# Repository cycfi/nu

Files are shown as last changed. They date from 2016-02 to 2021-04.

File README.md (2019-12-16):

The Nu Series Modular Active Pickups are hacker friendly, general purpose pickups 
that can be used in a variety of applications. These are active multichannel 
pickups with low impedance coils and integrated single-ended, low-power, 
low-noise preamplifier for each coil. The Neodymium-core pickups are low profile 
and modular. They can be used individually or in groups.

This is the next evolutionary stage of our flagship multichannel Neo pickup. The 
Nu sports better crosstalk performance using permalloy ring shields and even 
lower noise with improved discrete preamp design. Most importantly, they sound 
just as good as the original. Same coil, same magnetic structure.

The pickups are designed for polyphonic effects processing —one for each string 
(distortion, EQ, compressor, delay, pan, pitch-shift, etc). Such extensive 
processing is now very possible due to advances in digital signal processing and 
multi-channel audio interfaces and multi-track audio software becoming commonplace.

The modular pickups are not just for guitars. Nus can also be utilized for other 
musical instruments such as the bass guitar, harps, pianos, xylophones, etc. The 
Nus are perfect for fanned-fret electric guitars with the pickup poles positioned 
at various angles. 

Refer to this repository to get the Eagle libraries used in our schematic and pcb files: https://github.com/cycfi/eagle_common

This work is licensed under a [Creative Commons Attribution-NonCommercial 4.0 
International License](http://creativecommons.org/licenses/by-nc/4.0/).

http://www.cycfi.com/

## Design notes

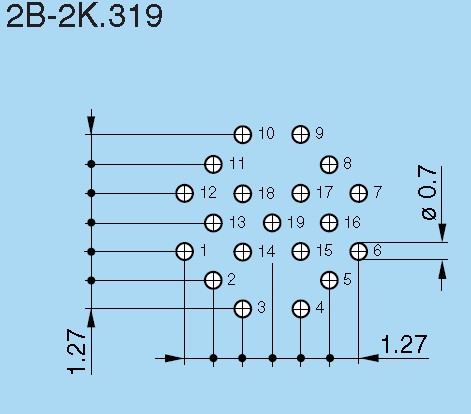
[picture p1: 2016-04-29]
references/19p_lemo_connector/sz_receptacle_90deg/pcb_pin_position.jpg

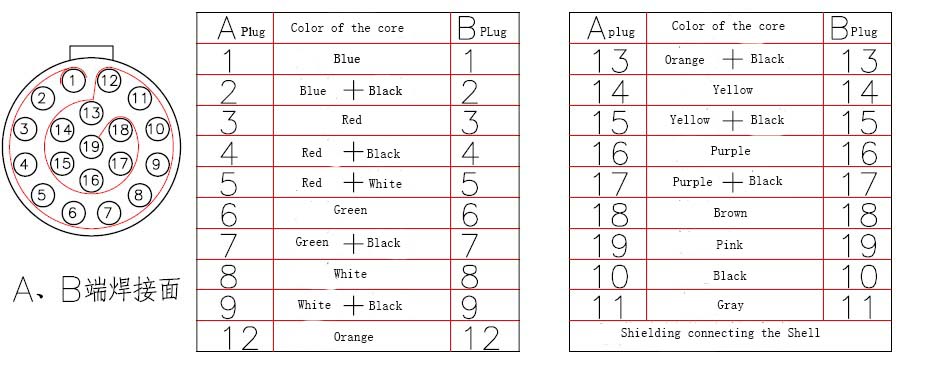
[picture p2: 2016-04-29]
references/19p_lemo_connector/sz_receptacle/pin_position_b.jpg

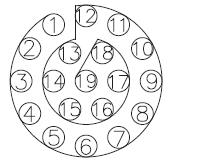
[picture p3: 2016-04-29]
references/19p_lemo_connector/sz_receptacle/pin_position_a.png

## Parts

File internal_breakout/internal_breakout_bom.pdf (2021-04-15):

INTERNAL BREAKOUT
Item | Description | Part Number | Packaging | Manufacturer | Location | Qty.
1 | 1uF | CC0603KRX5R8BB105 | C0603 | TDK | C3 | 1
2 | 10nF | CC0402KRX7R8BB103 | C0402 | Murata | C4 | 1
3 | 2.2uF | GRM188R6YA225KA12D | C0603 | Murata | C6 | 1
4 | 1nF | GCM155L81H102KA37D | C0402 | KEMET | C5 | 1
5 | 10uF | GRM188R61E106KA73D | C0603 | TDK | C1, C2 | 2
6 | 2x5 Male Header TH | M22-2580505 | 2.00mm | Harwin | J3, J4, J10, J11 | 4
7 | 1x3Male Header TH | 22-28-4035 | 2.54mm | Molex | J1, J2, J5, J6, J7, J8, J9, J10, J11, J12, J13, J14, J15 | 13
8 | P-Channel MOSFET | DMP3099L-7 | SOT-23-3 | Diodes Incorporated | Q1 | 1
9 | LDO Voltage Regulator | LP2985-10DBVR | SOT-23-5 | Texas Instruments | U1 | 1
10 | Ferrite Bead | BLM18KG700TN1D | R0603 | | FB1 | 1

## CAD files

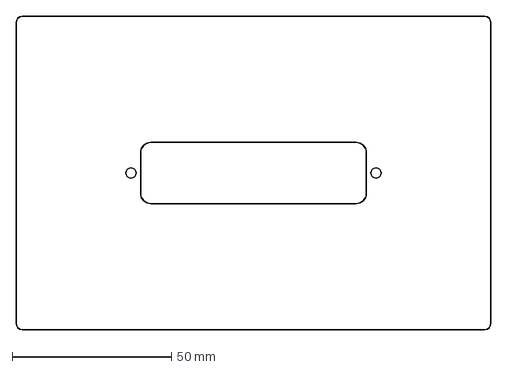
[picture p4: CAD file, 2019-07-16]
cad_drawings/nu_multi/Nu_Multi_6_Routing_Template_Drawing.DXF
149.2 x 98.4 mm

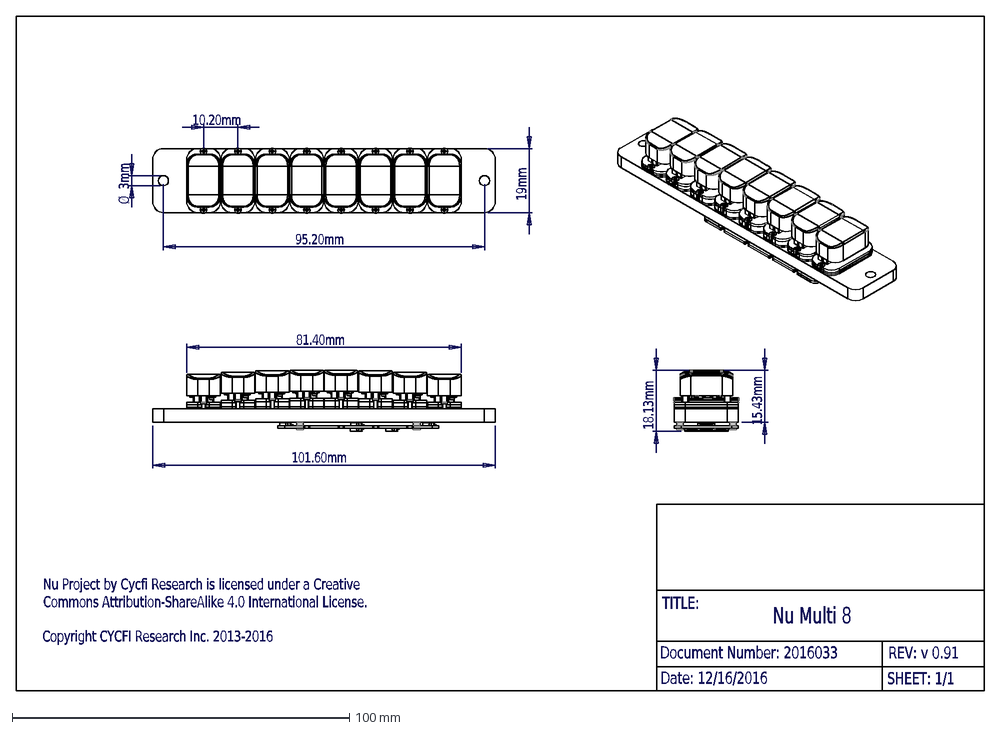
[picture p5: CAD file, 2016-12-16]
CAD_Drawings/Nu_Multi/Nu_Multi_8.dxf
Nu Project by Cycfi Research is licensed under a Creative
Commons Attribution-ShareAlike 4.0 International License.
Copyright CYCFI Research Inc. 2013-2016
Nu Multi 8
TITLE:
Document Number: 2016033
Date: 12/16/2016
REV: v 0.91
SHEET: 1/1
81.40mm
101.60mm
10.20mm
19mm
95.20mm
Ø
3mm
15.43mm
18.13mm

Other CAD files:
cad_drawings/nu_multi/nu_multi_7.DWG
cad_drawings/nu_multi/nu_multi_6.DWG
cad_drawings/nu_multi/nu_multi_8.DWG

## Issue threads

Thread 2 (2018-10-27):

Nu6_Multi.pdf?

olavkvern, 2018-10-27:
Hi CycFi--I'm finally getting around to putting a Nu Multi 6 pickup into a current project, and I came here looking for the technical drawings. The link to the Nu6_Multi.pdf file returns a 404 error, and I don't see the PDF here. Where would I find it?

Thanks,

Ole
okvern@ix.netcom.com

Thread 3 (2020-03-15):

incomplete BOM

bobwmcgrath, 2020-03-15:
Hello.  I am a long time fan of cycfi research's work.  I was curious about the construction of the pickup part of this nu capsule, but I do not see the "neodymium magnet, iron core, pickup coil, or permalloy ring"  that is shown on the website.   Can you please point me in the right direction to learn more about this?  Are these off the shelf parts or custom machined?  If they are custom made is there CAD information for the parts.  Thanks!

djowel, 2020-03-15:
Hi Bob, RIght. Well, these are not off the shelf parts, except for the neodymium magnet, which is kinda standard N52 disc types. We make these ourselves. We do have 3D drawings that I can place here.

bobwmcgrath, 2020-05-01:
That would be fantastic.

jonnor, 2022-11-05:
What are the rough specs on the coil? Size, inductance, etc? Would it be feasible at all to use off-the-shell inductor (SMD or throughhole) as a single string pickup?

djowel, 2022-11-06:
You can find the specs here:
https://www.cycfi.com/projects/nu-v2-capsule/

No, it is not possible to use off-the-shell inductors, or at least there's none that I know of that will fit the dimensions of the capsule and the magnet. I'm attaching the drawings for the coil.

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

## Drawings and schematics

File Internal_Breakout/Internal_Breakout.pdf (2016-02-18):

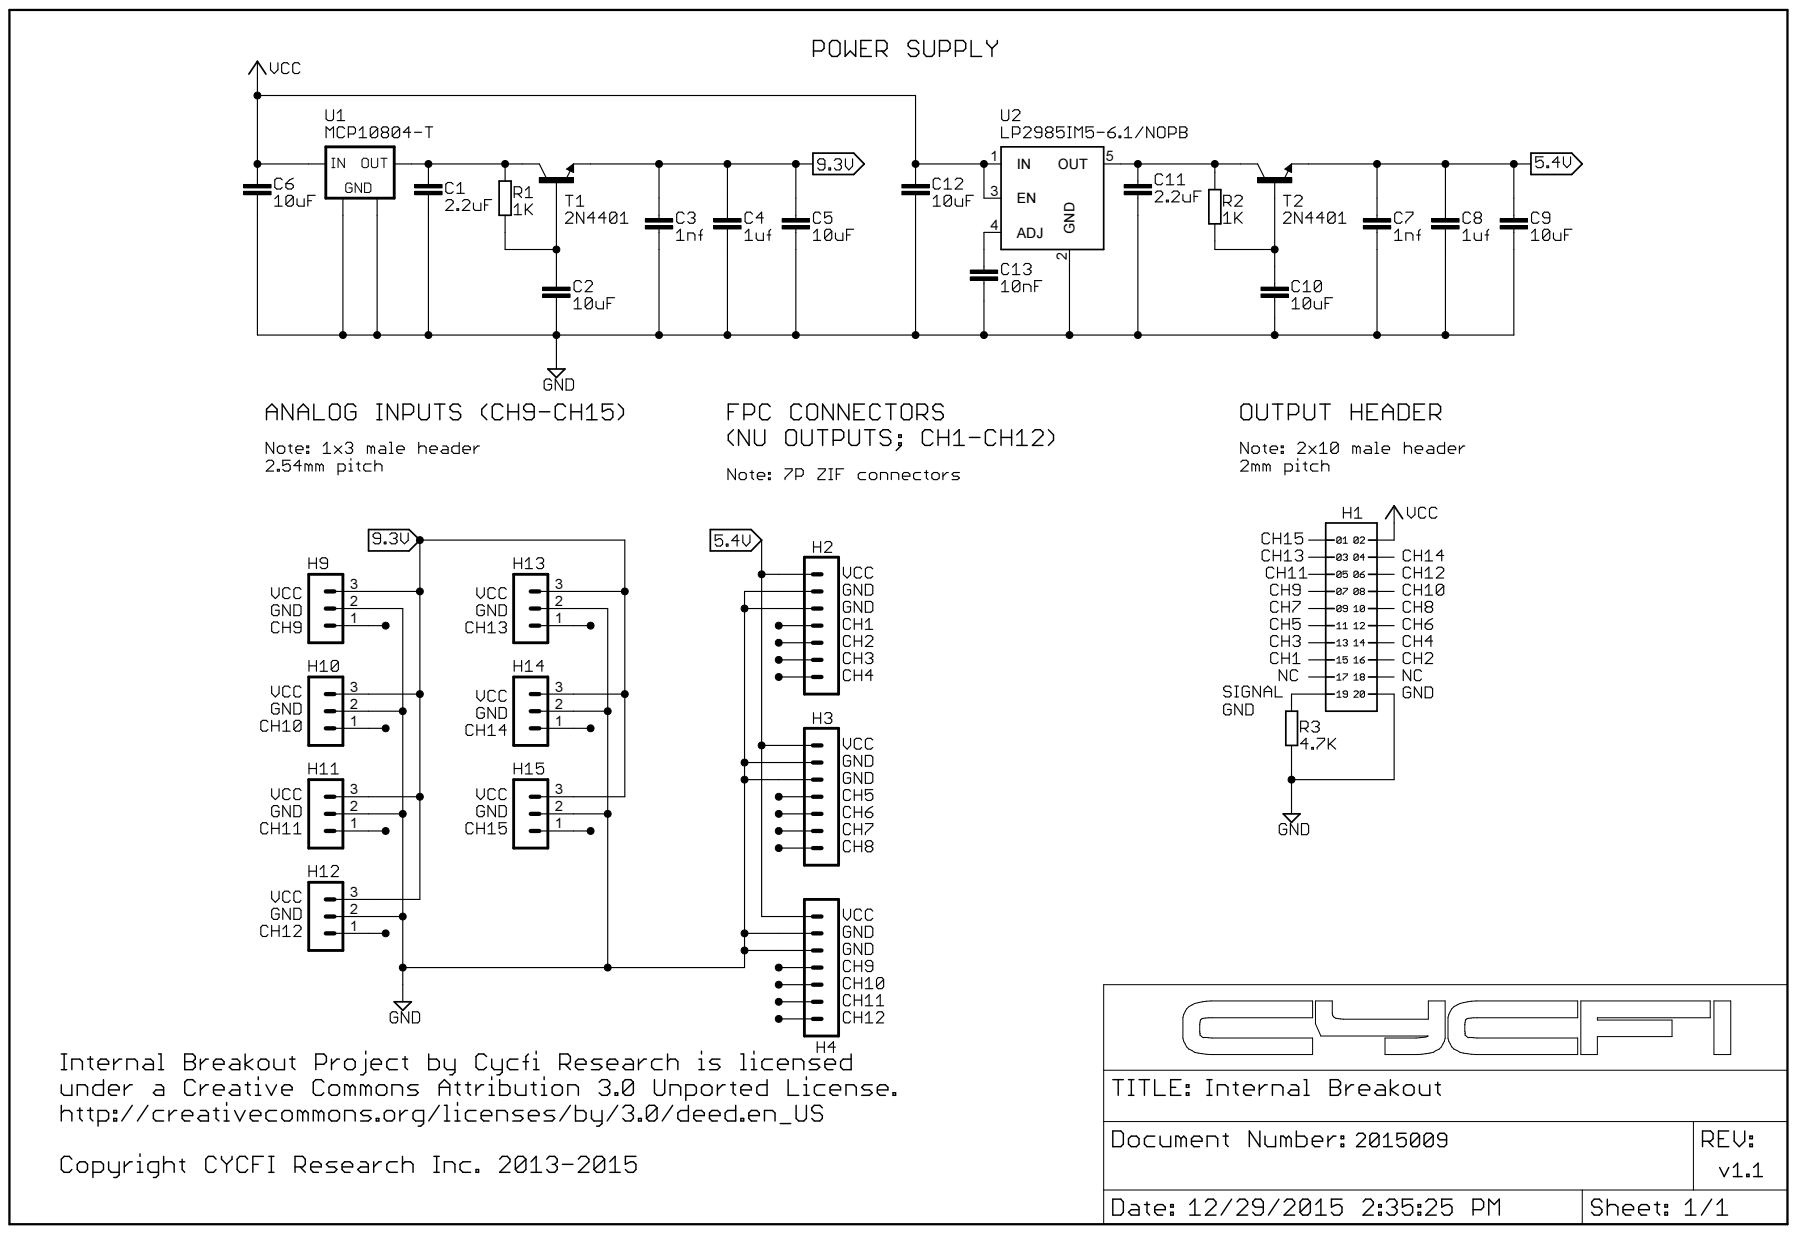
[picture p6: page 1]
OUT; ADJ; GND

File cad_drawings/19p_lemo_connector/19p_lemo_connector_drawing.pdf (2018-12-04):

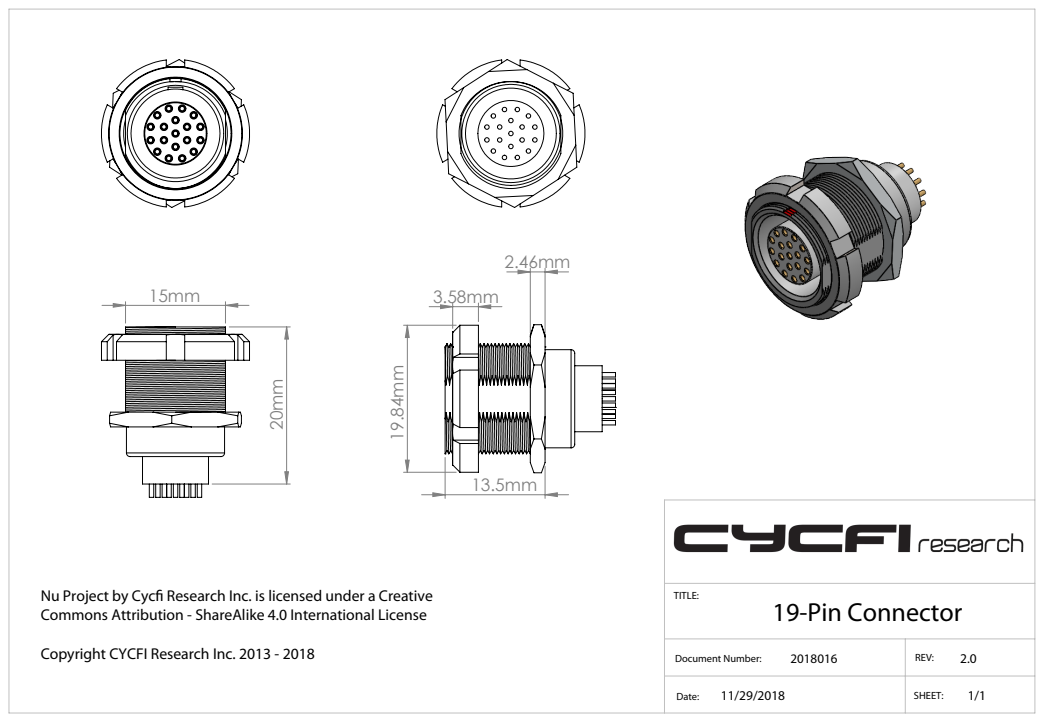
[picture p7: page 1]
19-Pin Connector; TITLE:

Nu Project by Cyc Research Inc. is licensed under a Creative
Commons Attribution - ShareAlike 4.0 International License

Copyright CYCFI Research Inc. 2013 - 2018

Document Number: 2018016 | REV: 2.0

11/29/2018 Date: | 1/1 SHEET:

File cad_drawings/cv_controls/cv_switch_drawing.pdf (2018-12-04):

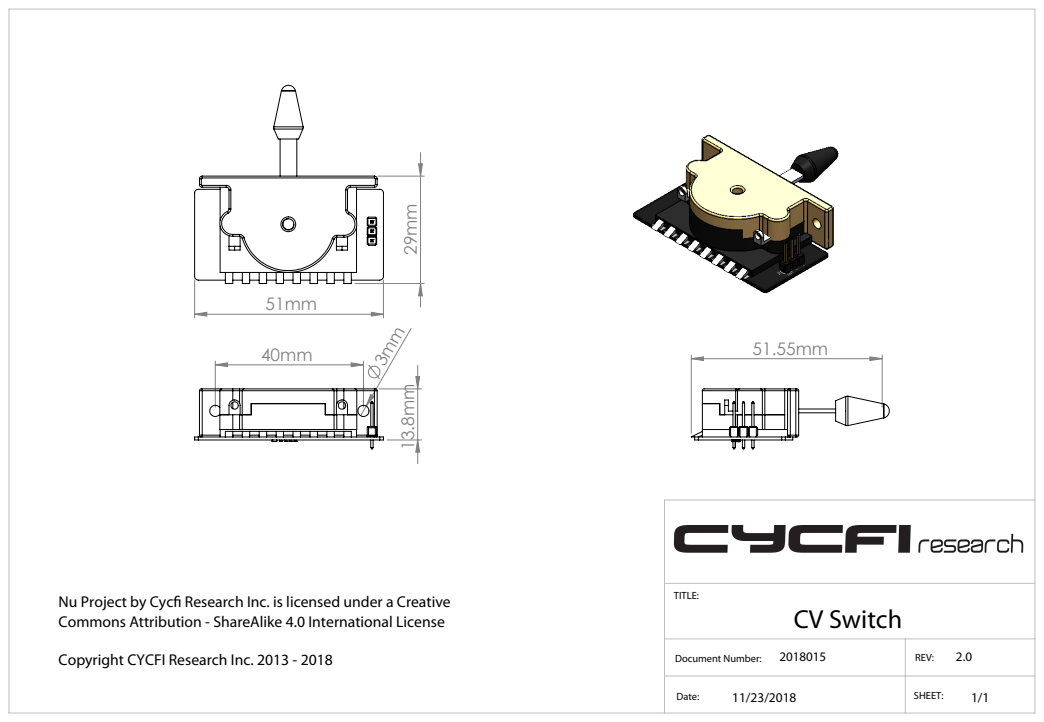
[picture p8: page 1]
CV Switch; TITLE:

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

Copyright CYCFI Research Inc. 2013 - 2018

Document Number: 2018015 2.0 | REV:

Date: 11/23/2018 | SHEET: 1/1

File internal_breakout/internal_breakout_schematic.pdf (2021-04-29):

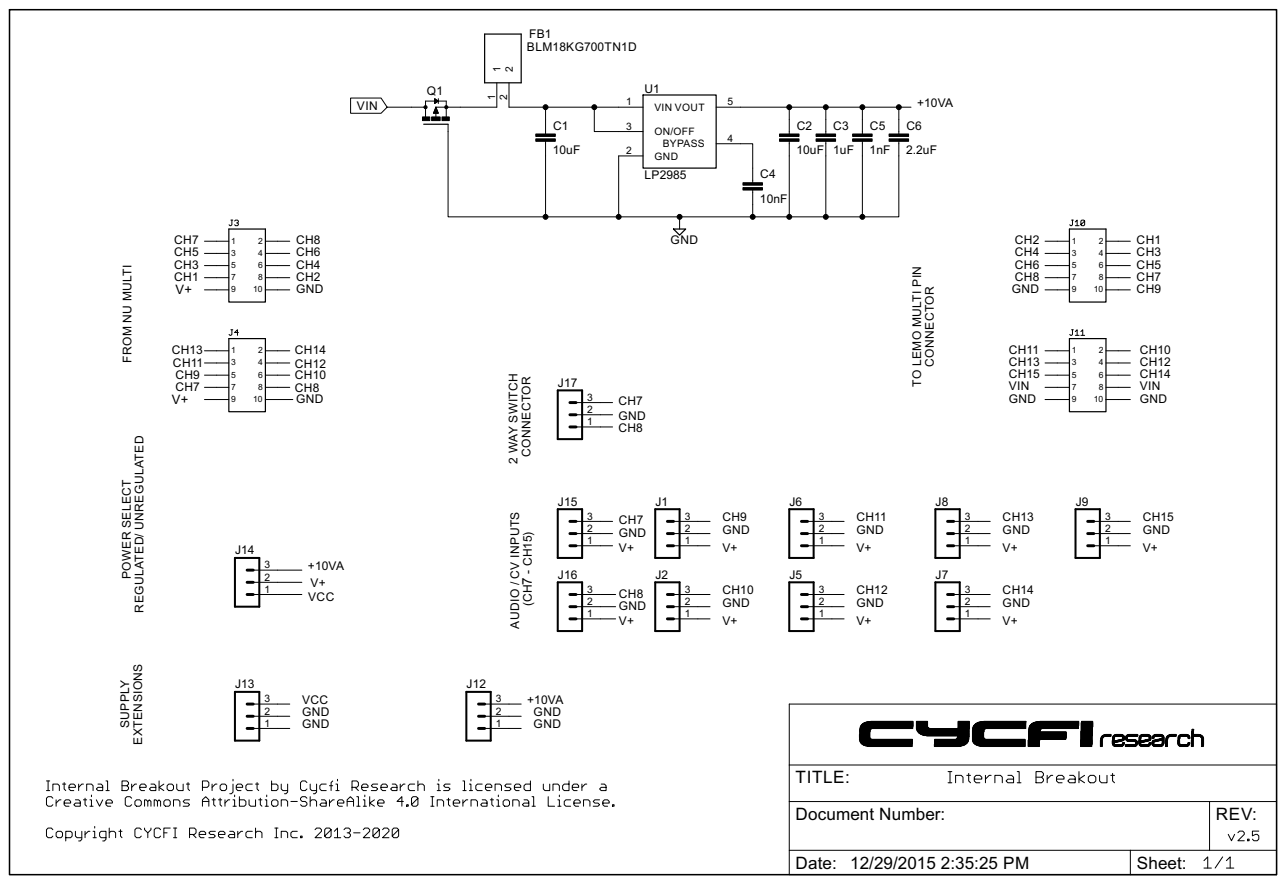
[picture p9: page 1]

Document Number: | REV:

Date: 12/29/2015 2:35:25 PM | Sheet:

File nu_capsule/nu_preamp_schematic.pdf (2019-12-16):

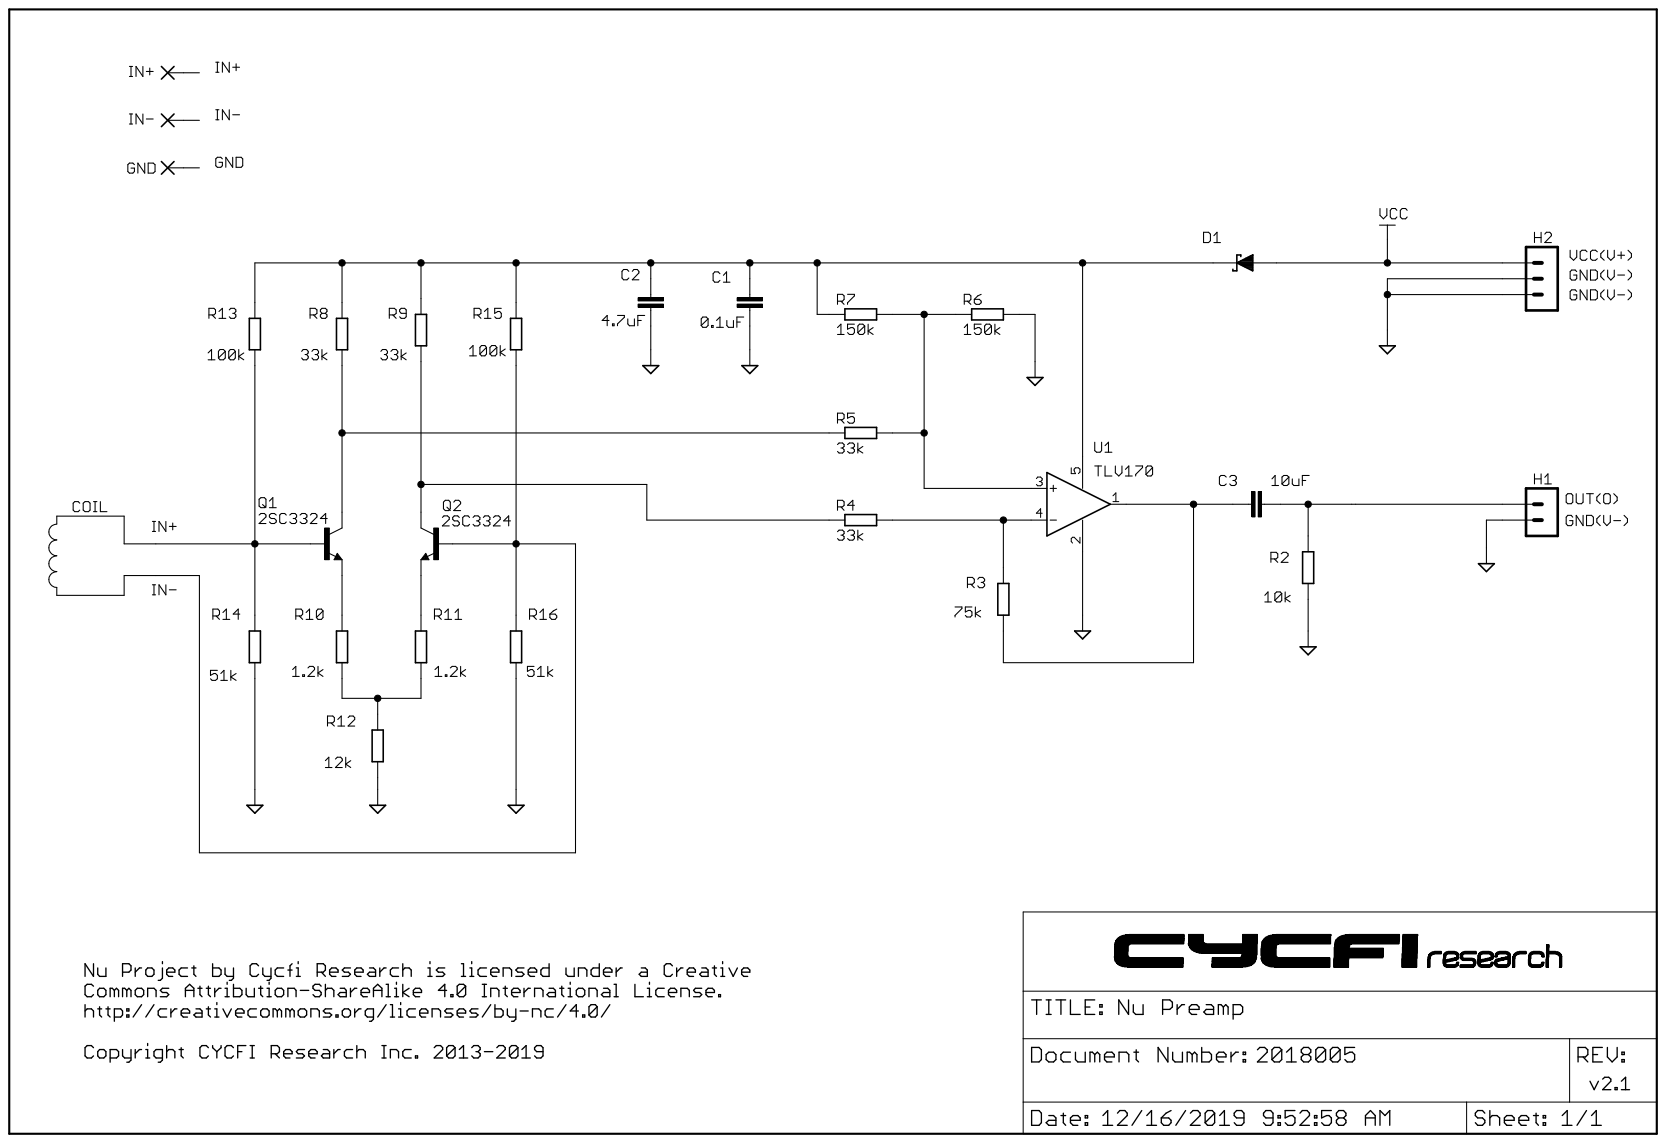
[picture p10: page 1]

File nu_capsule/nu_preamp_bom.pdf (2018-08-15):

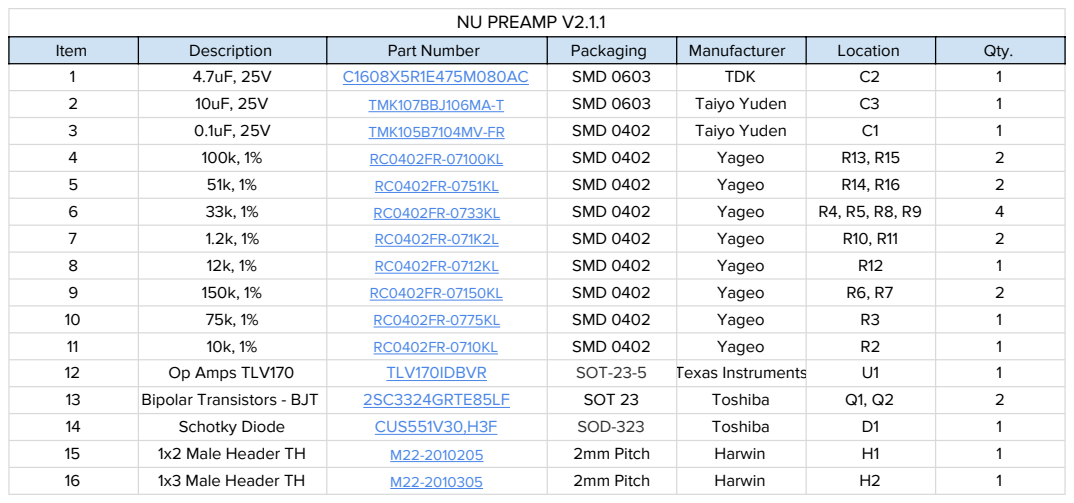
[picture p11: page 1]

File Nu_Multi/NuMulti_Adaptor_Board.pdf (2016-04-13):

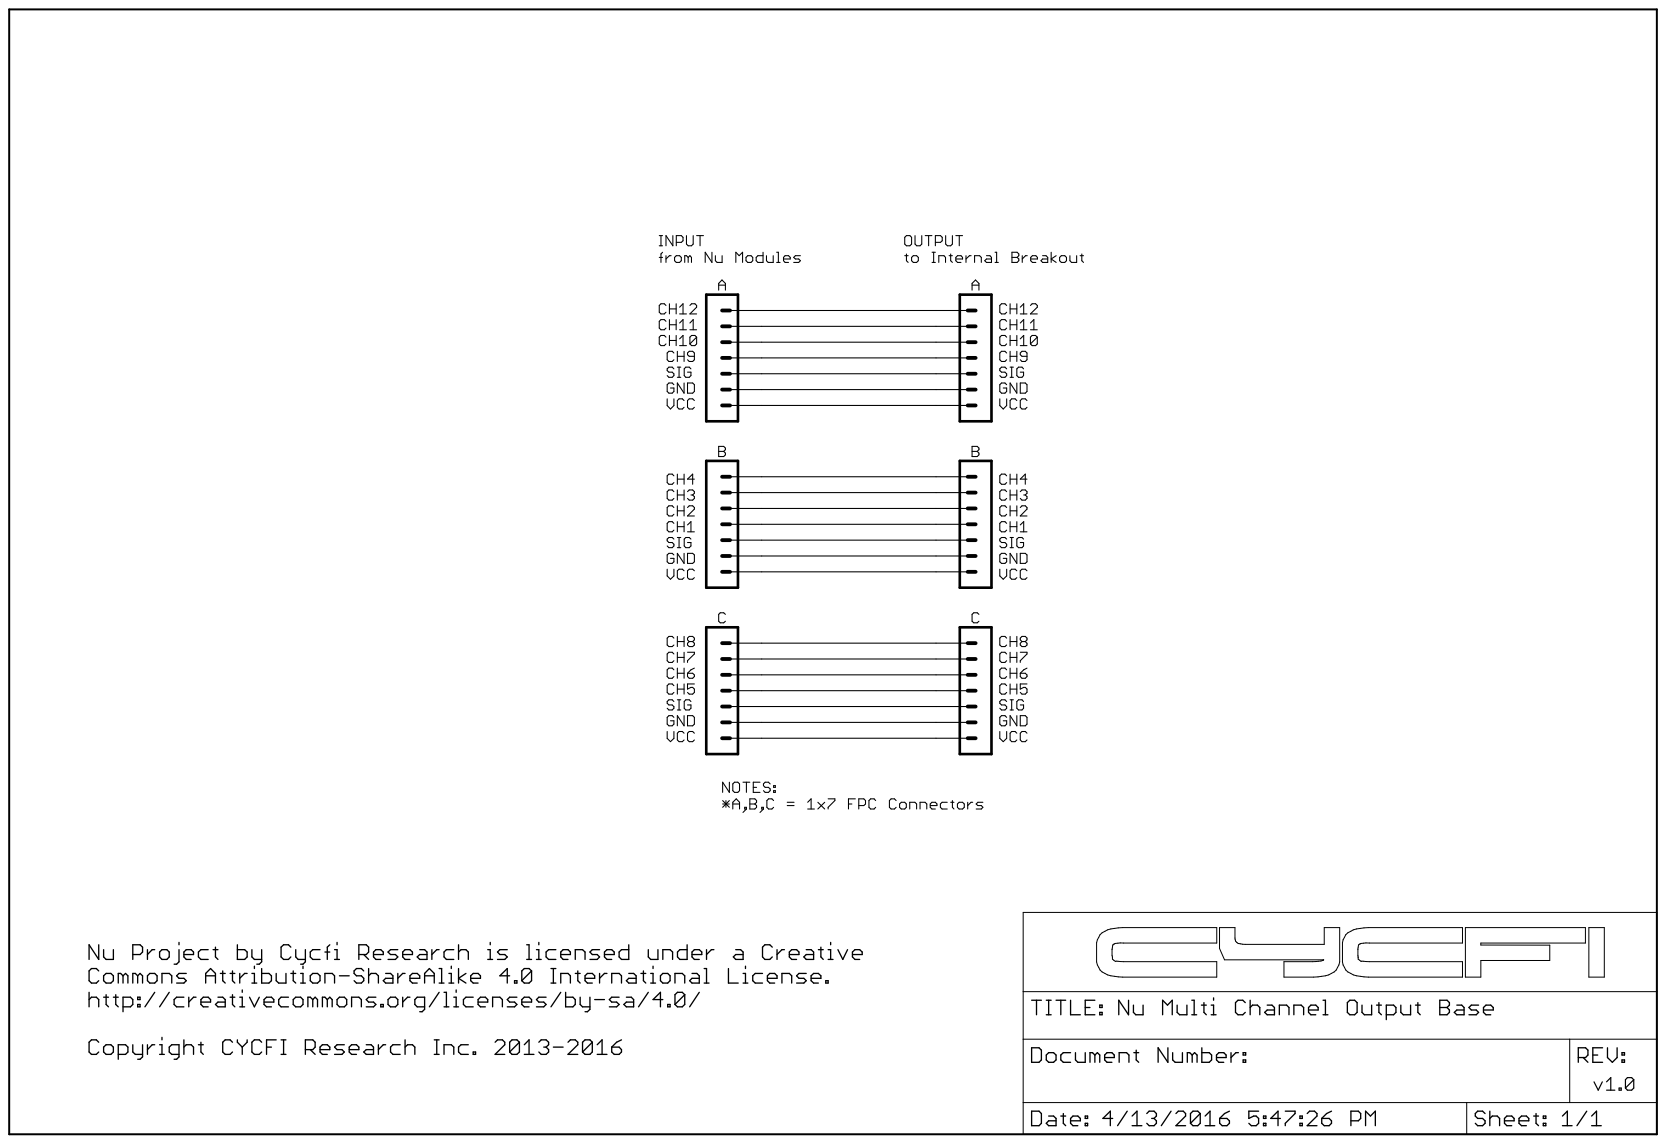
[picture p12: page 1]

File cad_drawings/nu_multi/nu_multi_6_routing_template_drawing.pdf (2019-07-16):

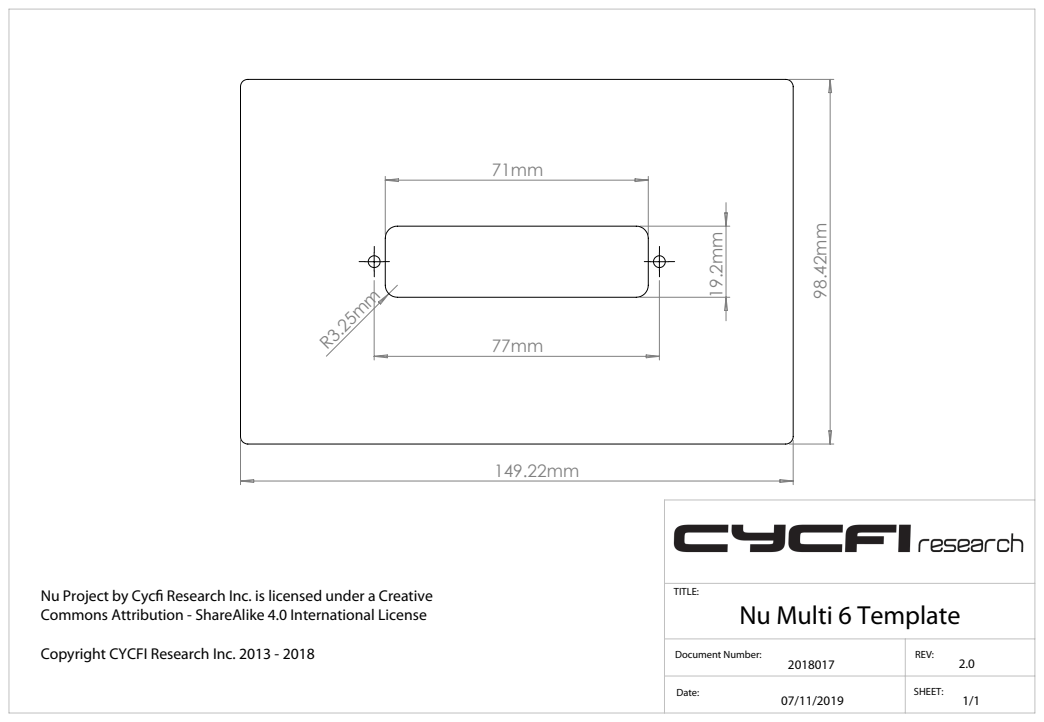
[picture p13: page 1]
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

TITLE:
Nu Multi 6 Template

Copyright CYCFI Research Inc. 2013 - 2018

Document Number: 2018017 | REV: 2.0

Date: 07/11/2019 | SHEET: 1/1

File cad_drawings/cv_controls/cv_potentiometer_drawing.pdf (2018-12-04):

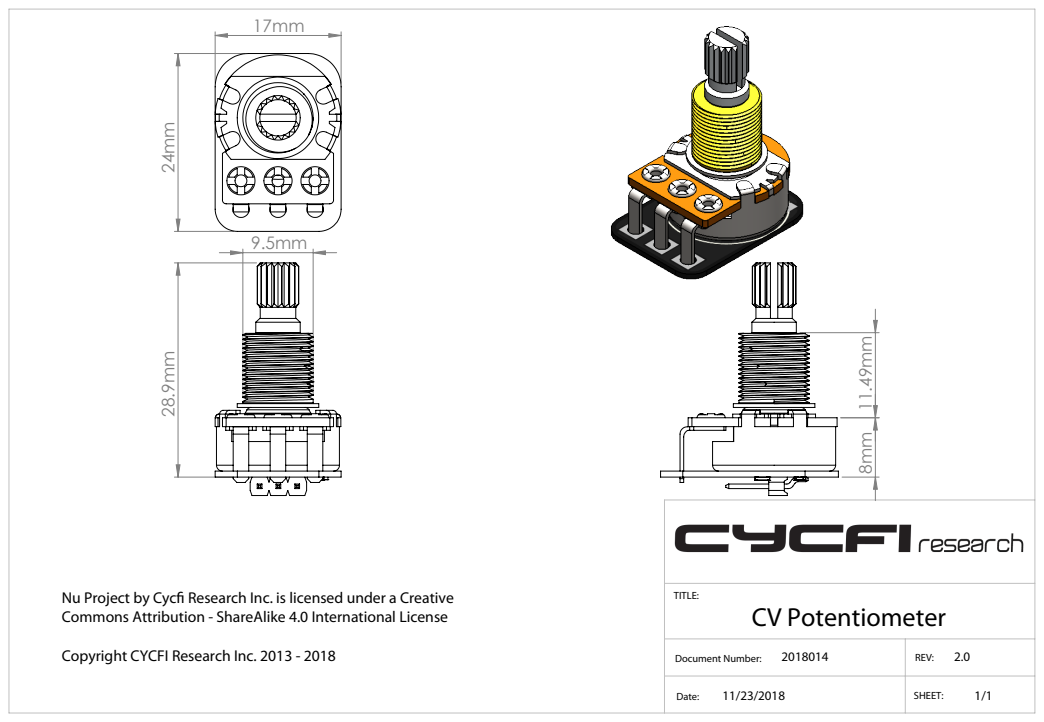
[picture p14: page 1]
CV Potentiometer; TITLE:

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

Copyright CYCFI Research Inc. 2013 - 2018

Document Number: 2018014 2.0 | REV:

Date: 11/23/2018 | SHEET: 1/1

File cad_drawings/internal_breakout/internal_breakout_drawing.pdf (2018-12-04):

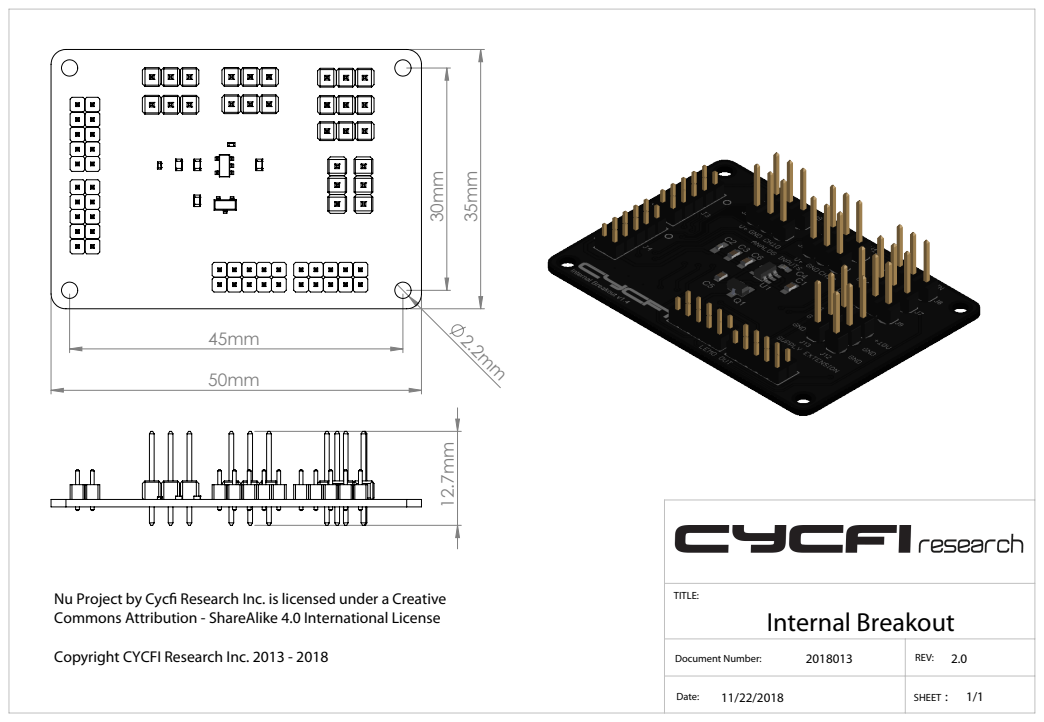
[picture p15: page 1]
Internal Breakout; TITLE:

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

Copyright CYCFI Research Inc. 2013 - 2018

Document Number: 2018013 | REV: 2.0

Date: 11/22/2018 | SHEET : 1/1

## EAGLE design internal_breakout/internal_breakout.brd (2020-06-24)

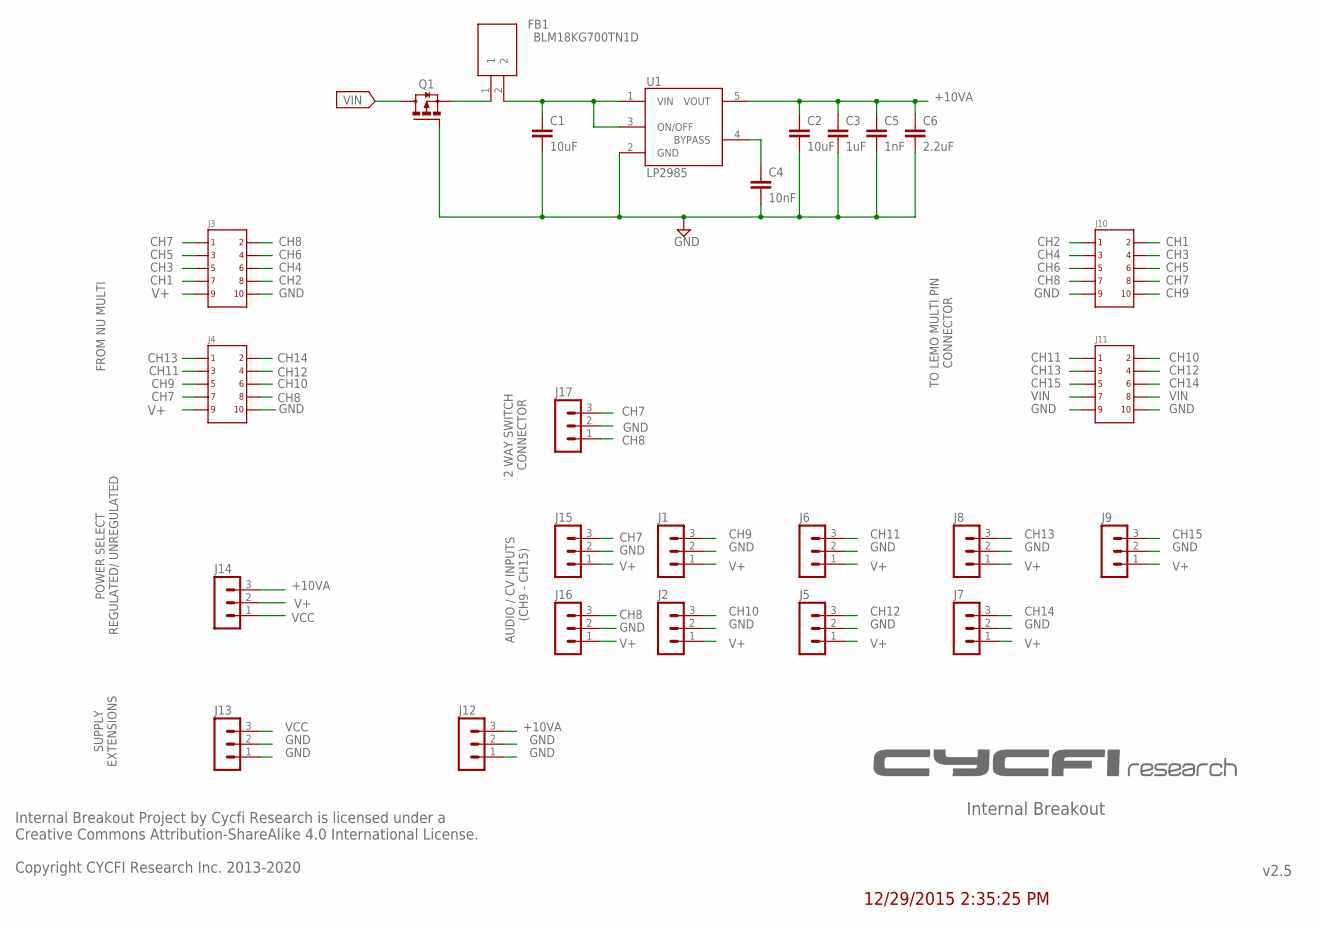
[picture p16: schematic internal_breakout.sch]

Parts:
C1, C2: 10uF; C0603
C3: 1uF; C0603
C4: 10nF; C0402
C5: 1nF; C0402
C6: 2.2uF; C0603
FB1: BLM18KG700TN1D; BEADC1608X75N
J1, J2, J5, J6, J7, J8, J9, J12, J13, J14, J15, J16, J17: MA03-1
J3, J4, J10, J11: 2X5
Q1: DMP3099L; SUPER-SOT3
U1: LP2985; SOT25

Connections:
+10VA: C2.1, C3.1, C5.1, C6.1, J12.3, J14.3, U1.5 (VOUT)
BYPASS: C4.1, U1.4 (BYPASS)
CH1: J3.7, J10.2
CH2: J3.8, J10.1
CH3: J3.5, J10.4
CH4: J3.6, J10.3
CH5: J3.3, J10.6
CH6: J3.4, J10.5
CH7: J3.1, J4.7, J10.8, J15.3, J17.3
CH8: J3.2, J4.8, J10.7, J16.3, J17.1
CH9: J1.3, J4.5, J10.10
CH10: J2.3, J4.6, J11.2
CH11: J4.3, J6.3, J11.1
CH12: J4.4, J5.3, J11.4
CH13: J4.1, J8.3, J11.3
CH14: J4.2, J7.3, J11.6
CH15: J9.3, J11.5
GND: C1.2, C2.2, C3.2, C4.2, C5.2, C6.2, J1.2, J2.2, J3.10, J4.10, J5.2, J6.2, J7.2, J8.2, J9.2, J10.9, J11.9, J11.10, J12.1, J12.2, J13.1, J13.2, J15.2, J16.2, J17.2, Q1.1 (G), U1.2 (GND)
unnamed: FB1.1, Q1.2 (S)
V+: J1.1, J2.1, J3.9, J4.9, J5.1, J6.1, J7.1, J8.1, J9.1, J14.2, J15.1, J16.1
VCC: C1.1, FB1.2, J13.3, J14.1, U1.1 (VIN), U1.3 (ON/OFF)
VIN: J11.7, J11.8, Q1.3 (D)

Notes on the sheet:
Internal Breakout
v2.5
Internal Breakout Project by Cycfi Research is licensed under a Creative Commons Attribution-ShareAlike 4.0 International License. Copyright CYCFI Research Inc. 2013-2020
12/29/2015 2:35:25 PM
CH1
CH3
CH5
CH7
GND
CH2
CH4
CH6
CH8
FROM NU MULTI
AUDIO / CV INPUTS (CH9 - CH15)
SUPPLY EXTENSIONS
TO LEMO MULTI PIN CONNECTOR
POWER SELECT REGULATED/ UNREGULATED
2 WAY SWITCH CONNECTOR

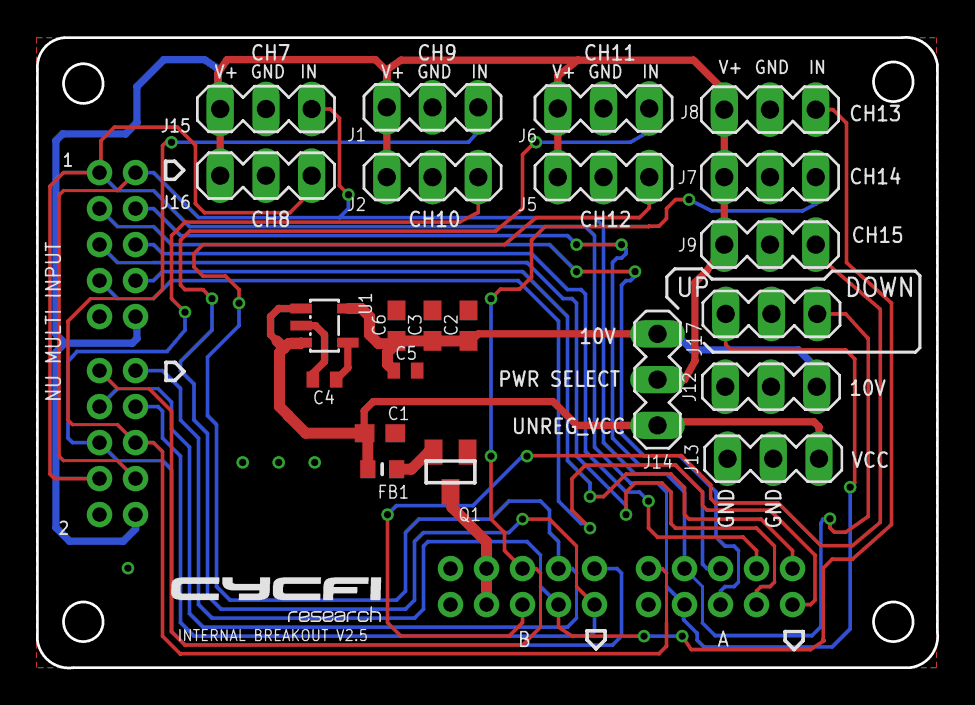
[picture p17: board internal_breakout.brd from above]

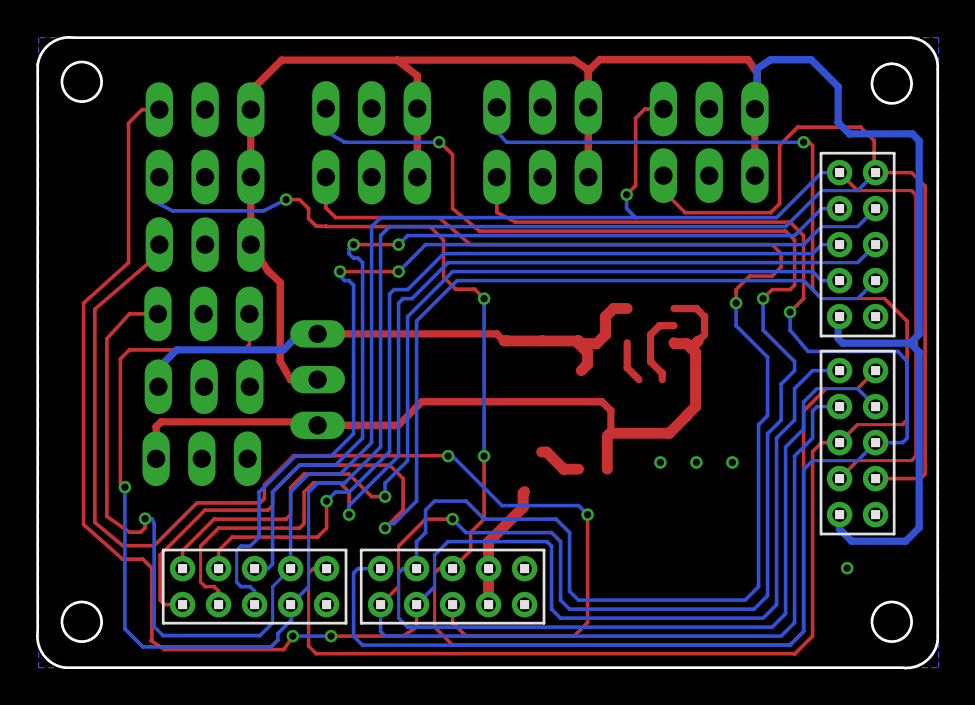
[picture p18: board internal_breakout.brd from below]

Board: 2 copper layers, 50.0 x 35.0 mm, 26 parts (4 on the bottom side), 22 nets.

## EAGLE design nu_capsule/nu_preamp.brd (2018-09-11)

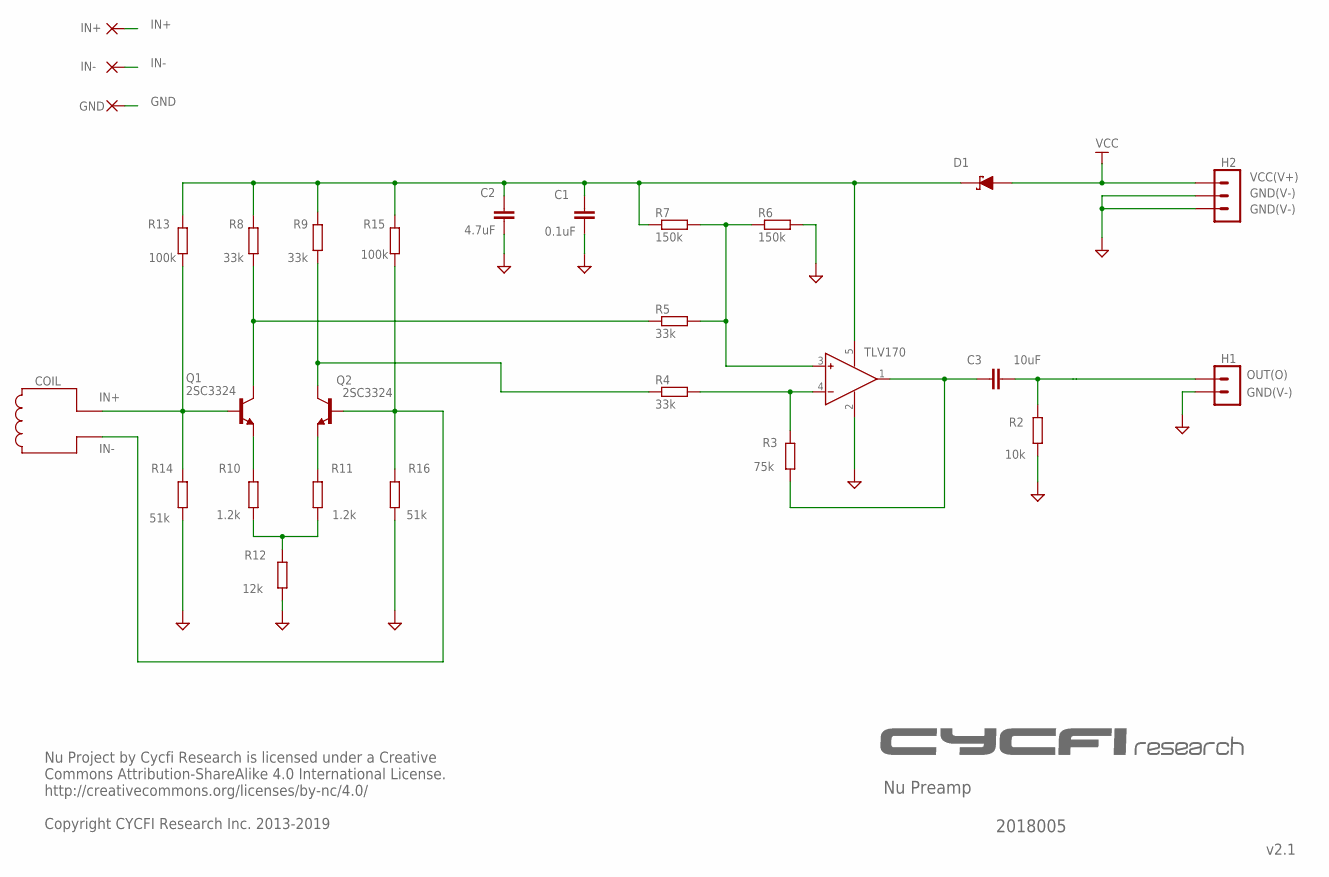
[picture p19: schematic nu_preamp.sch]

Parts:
C1: 0.1uF; C0402
C2: 4.7uF; C0603_NK
C3: 10uF; C0603_NK
D1: D_SCHOTTKYL; SOD-323
GND: SMD2; SMD1,27-2,54
H1: 2P-2MM-TH-MALE; 2P-2MM-TH
H2: 3P-2MM-TH-MALE; 3P-2MM-TH
IN+: SMD2; SMD1,27-2,54
IN-: SMD2; SMD1,27-2,54
Q1, Q2: 2SC3324; SOT23
R2: 10k; R0402
R3: 75k; R0402
R4, R5, R8, R9: 33k; R0402
R6, R7: 150k; R0402
R10, R11: 1.2k; R0402
R12: 12k; R0402
R13, R15: 100k; R0402
R14, R16: 51k; R0402
U1: TLV170; SOT23-5

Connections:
GND: C1.2, C2.1, GND.1, H1.P$2 (2), H2.P$2 (2), H2.P$3 (3), R2.1, R6.2, R12.1, R14.1, R16.1, U1.2 (V-)
IN+: IN+.1, Q1.1 (B), R13.1, R14.2
IN-: IN-.1, Q2.1 (B), R15.1, R16.2
unnamed: C3.2, H1.P$1 (1), R2.2
unnamed: Q1.3 (C), R5.1, R8.1
unnamed: Q2.3 (C), R4.1, R9.1
unnamed: Q1.2 (E), R10.2
unnamed: Q2.2 (E), R11.2
unnamed: R10.1, R11.1, R12.2
unnamed: R5.2, R6.1, R7.2, U1.3 (IN+)
unnamed: R3.2, R4.2, U1.4 (IN-)
unnamed: C3.1, R3.1, U1.1 (OUT)
unnamed: D1.1 (A), H2.P$1 (1)
VCC1: C1.1, C2.2, D1.2 (C), R7.1, R8.2, R9.2, R13.2, R15.2, U1.5 (V+)

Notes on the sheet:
Nu Preamp
v2.1
Nu Project by Cycfi Research is licensed under a Creative Commons Attribution-ShareAlike 4.0 International License. http://creativecommons.org/licenses/by-nc/4.0/ Copyright CYCFI Research Inc. 2013-2019
VCC
COIL
VCC(V+)
GND(V-)
OUT(O)
IN+
IN-
2018005

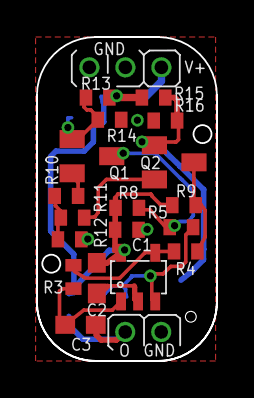
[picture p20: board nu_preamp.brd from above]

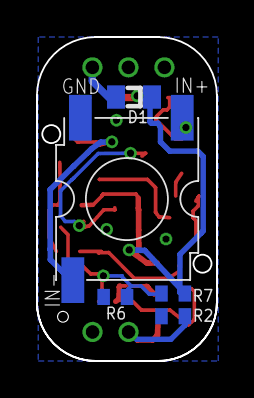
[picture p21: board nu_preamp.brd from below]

Board: 2 copper layers, 10.0 x 18.0 mm, 27 parts (7 on the bottom side), 14 nets.

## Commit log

2016-02-01 Initial Commit. Nu Project.
    [Nu1 Capsule Drawing.DXF, Nu1 Capsule.brd, Nu1 Capsule.sch]
2016-02-01 Renamed files (Nu1 to Nu)
    [Nu Capsule Drawing.DXF, Nu Capsule.brd, Nu Capsule.sch]
2016-02-01 Renamed files to not contain spaces
    [Nu_Capsule.brd, Nu_Capsule.sch, Nu_Capsule_Drawing.dxf]
2016-02-02 Doc updates
    [Nu_Capsule.brd, Nu_Capsule.sch]
2016-02-02 updates and minor corrections
    [Nu_Capsule.brd, Nu_Capsule.sch]
2016-02-02 more updates; tweaks
    [Nu_Capsule.brd, Nu_Capsule.sch]
2016-02-18 added internal breakout and module drawings
    [Internal_Breakout.brd, Internal_Breakout.sch, Nu_Module_Drawing.dxf]
2016-02-19 Added Multi
    [Nu8_Multi.dxf]
2016-03-16 added bottom view (shwoing PCB and some dimensions)
2016-04-13 Added files via upload
    Additional Files for Nu multi Release
    [NuMulti_Adaptor_Board.brd, NuMulti_Adaptor_Board.sch]
2016-04-13 Added files via upload
    Fix Licenses
    [NuMulti_Adaptor_Board.sch]
2016-10-07 GK Roland Breakout and Nu Duo documents
    [GK_Roland_Breakout.brd, GK_Roland_Breakout.sch, Nu_Duo.brd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]
2016-10-15 Added CAD
    [Nu8_Multi.dxf, Nu_Capsule_Drawing.dxf, Nu_Module_Drawing.dxf]
2016-11-08 Update drawings
    [Nu_Baseplate.dxf, Nu_Capsule.dxf, Nu_Duo_6.dxf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]
2016-12-05 remove caption
    [Nu_Multi.brd, Nu_Multi.sch]
2016-12-16 Update drawings, change of Nu Preamp and Coil Base PCB
    [Nu_Baseplate.dxf, Nu_Capsule.dxf, Nu_Duo_6.dxf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]
2017-02-07 Added 3D for Nu Multi
    [Active_Base.SLDASM, Active_Base_PCB.SLDPRT, Caps.SLDPRT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]
2017-02-14 *update license date
    [GK_Roland_Breakout.sch, Internal_Breakout.sch, Nu_Capsule.sch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]
2017-05-08 Added module mounting hole dimensions.
2017-06-01 Added Nu_Module folder and files
    [Nu_Module.brd, Nu_Module.sch]
2017-09-05 Updated BOM
    [13P_Connector.brd, 13P_Connector.sch, GK_Roland_Breakout.brd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]
2017-09-05 Updated Notes "For Nu Project" instead of "Nexus"
    [13P_Connector.sch, GK_Roland_Breakout.sch, Internal_Breakout.sch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]
2017-09-05 Updated document number.
    [13P_Connector.sch, GK_Roland_Breakout.sch, Internal_Breakout.sch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]
2017-09-05 Updated BOM, Copyright and Document Number
2018-08-14 Updated files for version 2.0
    [Nu_Preamp.brd, Nu_Preamp.sch]
2018-08-14 Updated document number for Nu Preamp v2.0
    [Nu_Preamp.sch]
2018-08-14 Updated Internal Breakout Files
    [Internal_Breakout.brd, Internal_Breakout.kicad_pcb, Internal_Breakout.sch]
2018-08-14 Files not related to this version removed
    [13P_Connector.brd, 13P_Connector.sch, Active_Base.SLDASM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]
2018-08-14 Updated Nu Preamp Files
    [Nu_Preamp.brd, Nu_Preamp.sch]
2018-08-14 Document number added
    [Nu_Preamp.sch]
2018-08-14 Updated pdf of the schematic
2018-08-15 Updated files for Nu Preamp v2.1.1 added
    [Nu_Preamp.brd, Nu_Preamp.sch]
2018-08-22 Updated Nu Multi Output Board added
    [Connector Board.kicad_pcb, Connector Board.sch]
2018-09-01 Updated files pushed
    [Output_Board.kicad_pcb, Output_Board.sch]
2018-09-11 Remove commas and voltage rating on capacitor symbols on schematics
    [Nu_Preamp.brd, Nu_Preamp.sch]
2018-09-12 Reverted Internal Breakout to Eagle
    [Internal Breakout.brd, Internal_Breakout.kicad_pcb, Internal_Breakout.sch]
2018-09-13 Internal Breakout slight changes
    [Internal Breakout.brd]
2018-09-13 Slight Changes to Internal Breaout
    [Internal Breakout.brd]
2018-09-14 Slight changes to Internal Breakout
    [Internal Breakout.brd, Internal_Breakout.sch]
2018-10-25 Fixed labels on internal breakout
    [Internal_Breakout.brd, Internal_Breakout.sch]
2018-11-24 Push Nu CAD drawings to devel
2019-06-06 fix schematic issue, connector's triangle marking must to pin 1 of the header in the schematic
    [Internal_Breakout.brd, Internal_Breakout.sch]
2019-07-16 Update Nu Multi 6 Routing template , added a dxf file also
    [Nu_Multi_6_Routing_Template_Drawing.DXF]
2019-11-15 folder renames
    [internal_breakout.brd, internal_breakout.sch, nu_preamp.brd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]
2019-12-16 push updated Nu preamp schematic files
    [Nu_Preamp.sch]
2020-02-05 push updated files for internal breakout
    [internal_breakout.brd, internal_breakout.sch]
2020-02-06 update bom
2020-06-21 update internal breakout files
    [internal_breakout.brd, internal_breakout.sch]
2020-06-24 update internal breakout with special header for 2 way switch
    [internal_breakout.brd, internal_breakout.sch]
2021-04-15 add bom file
2021-04-29 Update fix: Audio/CV now starts at CH7
    [internal_breakout.sch]

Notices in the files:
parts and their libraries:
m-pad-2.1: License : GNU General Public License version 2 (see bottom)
